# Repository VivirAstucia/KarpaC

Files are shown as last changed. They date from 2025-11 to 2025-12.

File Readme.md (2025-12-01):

# KarpaC - Prototype1
This is a smart chessboard project that takes chess to the next level by integrating a physical board with a digital interface. 

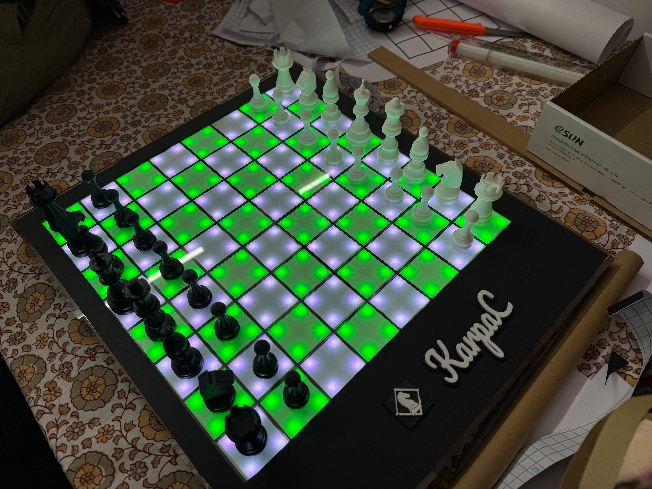
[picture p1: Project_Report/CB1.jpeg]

  
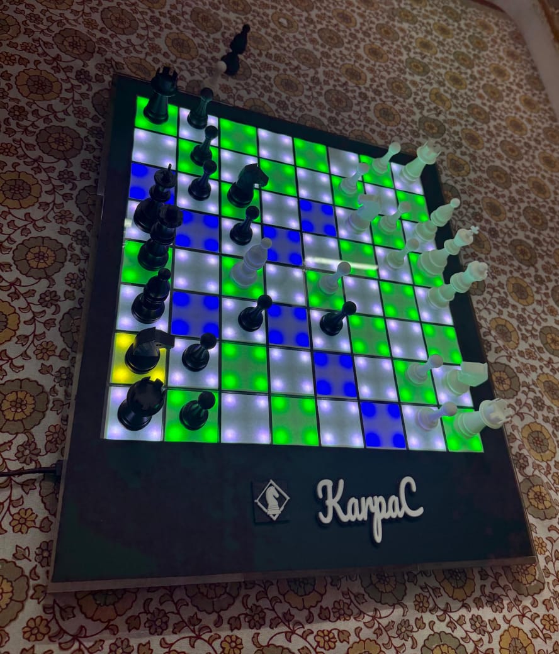
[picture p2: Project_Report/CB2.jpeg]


## Features
- **Real-time Game Tracking**: Automatically detects and records moves made on the physical board.
- **Digital Interface**: Provides a user-friendly interface to view and analyze games.
- **Move Validation**: Ensures that all moves made are legal according to chess rules.
- **Against Computer**: Play against a computer opponent with adjustable difficulty levels.
- **Game Analysis[TODO]**: Offers insights and suggestions based on the game state.
- **Multiplayer Support[TODO]**: Allows multiple players to join and play together online.

## Implementation
### Hardware
1. **Hall Effect Sensors**: Used to detect the position of chess pieces on the board.
2. **Ws2812B LEDs**: RGB LEDs for visual feedback and effects.
3. **Raspberry Pi 4b**: Acts as the main controller for processing inputs and managing the game state.
4. **Chess Pieces**: 3d printed pieces with embedded neodymium magnets for reliable detection.
5. **Chessboard**: A simple but elegant design with acrylic surfaces.
6. **Power Supply**: A 5V 3A power supply to power the Raspberry Pi and LEDs.

### Software
1. **Python**: Main programming language for the project.
   - `RPi.GPIO`, `chess`, `neopixel`
2. **Flask**: Web framework for creating the digital interface.
3. **Stockfish**: Chess engine for game analysis and computer opponent.

### Logic
1. **Current State**: Used boundary condition + pick/place data to determine the current state of the board.
2. **Move Detection**: Compares the previous and current state to detect moves.
3. **Move Validation**: Uses the `chess` library to validate moves.

## Issues and Fixes
- **Hall Sensor** - H[1][5] was not working in the pcb, and since no spare were available, it is set to always on in the code.
- **Temperature** - The board tends to heat up after prolonged use(40-50 mins). Since no ventilation was designed on the prototype.

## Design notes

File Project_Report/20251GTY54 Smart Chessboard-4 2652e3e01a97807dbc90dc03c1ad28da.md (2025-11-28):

# 20251GTY54: Smart Chessboard-4

**An MEP1001 project manufactured by** 

**Professor - Sunil Jha**

**TA - Devesh, Priyansh**

**Group - 29**

**Team -** 

**Priyanshu Raj (Group Leader)**

**Raghav Agarwal**

**Aadit Prakash Bhagade**

**Patil Kshitij Nikesh**

**Anuroop Dixit**

**2025MT11771**

**2025MT11351**

**2025CS11115**

**2025CS51201**

**2025MT11348**

---

# Navigation

---

# Market Research

## ChessNut Move

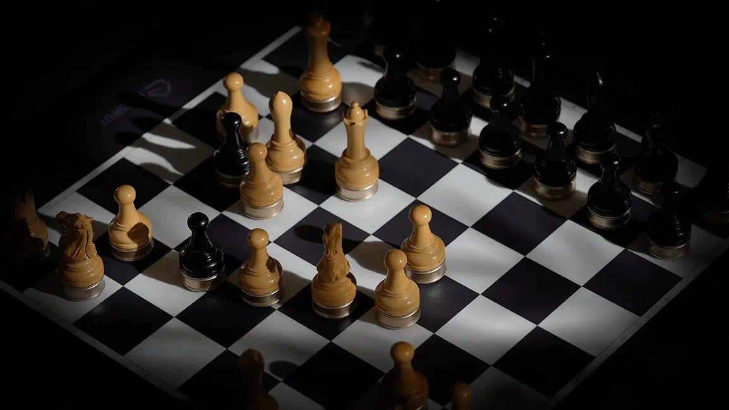
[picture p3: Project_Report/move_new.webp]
Source - [ChessNutech.com](https://www.chessnutech.com/)


Source - [ChessNutech.com](https://www.chessnutech.com/)

This board specializes in self-moving pieces. The pieces have little wheels attached at the bottom, which can be used to travel to any square on the board, even controlling the other pieces if necessary to move out of the way. It is also integrated with websites like [chess.com](http://chess.com/) and [lichess.org](http://lichess.org/) and can be used to play games and puzzles alike.

### Product Specifications: -

- Size: 63.2 cm x 52 cm x 2.2 cm
- Piece material: wood or plastic
- Features:
    - Automatic chess piece movement
    - Full piece recognition
    - Video integration
- Price: 53,000 INR

## GoChess

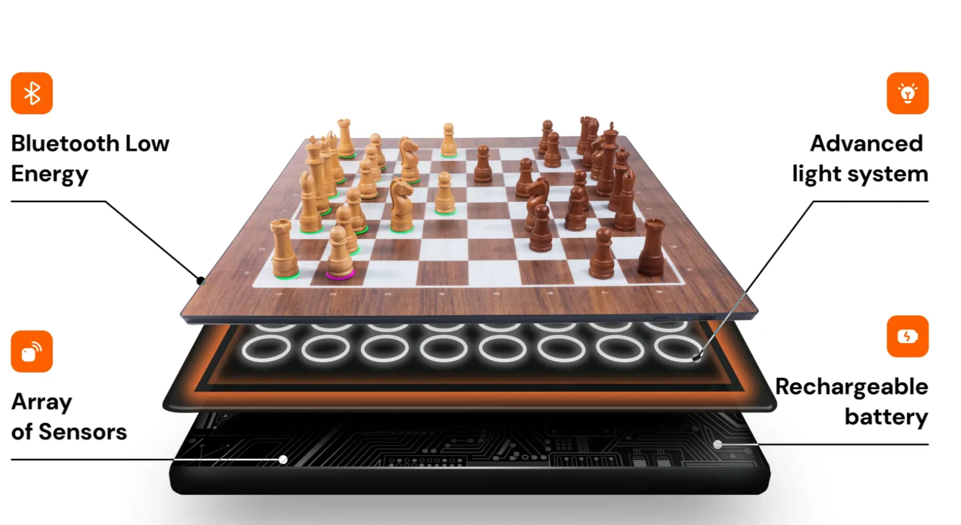
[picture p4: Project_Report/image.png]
Source - [GoChess](https://particula-tech.com/pages/gochess)


Source - [GoChess](https://particula-tech.com/pages/gochess)

A board focused on movement, recognition and suggestion, GoChess uses an enhanced motion technology to provide a comfortable user experience. It also displays the possible moves for a player once a piece is picked up. It is a one-of-a-kind product, that can be utilised in both online and in-player modes.

### Product Specification: -

- Board Size: 48 cm × 48 cm × 3.5 cm (standard) / 48 cm × 48 cm × 0.9 cm (slim model)
- Square Size: 4.8 cm × 4.8 cm
- Piece Material: Wooden and Plastic (Classic and Modern styles)
- Board Material: High quality plastic
- Sensors: Magnetic/Hall effect sensors to detect piece placement
- Connectivity: Bluetooth (BLE)
- Battery: Rechargeable (user serviceable) battery
- Charging Port: USB-C
- App Compatibility: iOS, Android, Web
- Price: 50,000 INR

### Features: -

- Self-moving pieces
- Intelligent Coaching lights
- App integration

## ChessUp

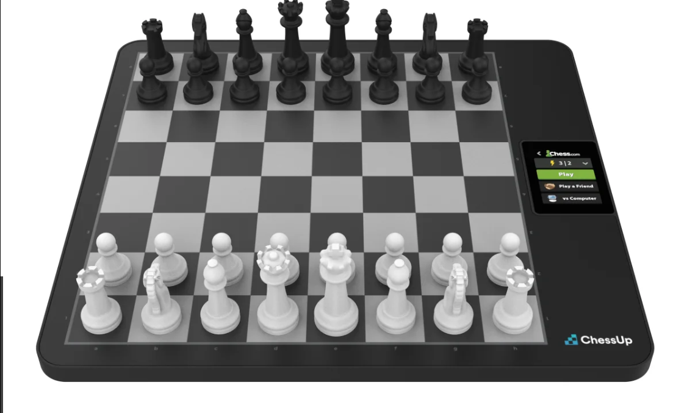
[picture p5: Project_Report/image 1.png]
Source - [PlayChessUp](https://playchessup.com/)


Source - [PlayChessUp](https://playchessup.com/)

The ChessUp board, affiliated with [chess.com](http://chess.com/) itself, is a new and innovative way to play chess. It excels at suggesting and recognizing moves. It can be connected with the [chess.com](http://chess.com/) server and can be used to play live games, over-the board, puzzles and bots. It provides the facility of adhering to all fair-play regulations according to its parent-company’s policy.

### Product Specification: -

- Weight: 1.13 kg
- Playable Area: 30.5cm × 30.5cm
- Square Size: 38.1 mm
- Battery Lifetime: 6 hours (USB‑C rechargeable)
- Connectivity: Wi‑Fi + Bluetooth
- Included Pieces: 34 with recognition chips
- Integration: Built-in Chess.com, some support for Lichess, no phone needed
- Price - Rs 35,125 INR

### Key Features: -

- Size: 39.6cm × 34.6cm × 1.8cm
- Touch sensing
- LED guidance
- AI training
- Touchscreen UI
- Stockfish integration

---

# Our Product - KarpaC

A smart-board which is light, seamlessly integrable with [chess.com](http://chess.com/) and [lichess](http://lichess.org/), connected to Stockfish, aesthetically pleasing and intelligent. It recognizes moves played and provides best-move suggestions by lighting up squares. It can be used for both over-the-board and online play. Its affordable nature sets it apart from its competitors.

## Product Specifications -

- Board Size: 36 cm * 40 cm * 5 cm
- Square Size: 4 * 4 cm
- Weight: Less than 2 kg
- Piece Material: 3D Printer Filament
- Board Material: Acrylic
- Sensors: Hall effect sensors to detect piece placement.
- Connectivity: Bluetooth (BLE) and Wi-Fi through ESP 32
- Battery: 4000mAh rechargeable battery (6+ hours of playtime)
- Charging Port: USB-C
- App Compatibility: iOS, Android, Web

## Key Features -

- LED move indicators
- Automatic Move Detection
- Inbuilt Chess Engine (Stockfish 15).
- Legal moves and best move suggestions.
- Buzzer sound on an illegal/invalid move.
- Integrated with chess.com and [lichess.org](http://lichess.org/) through Wi-Fi

## Initial Production Cost Estimate - 10,275 **INR**

| **Item** | **Function** | **Quantity** | Rate | Net Price |
| --- | --- | --- | --- | --- |
| LED ([WS2812B](https://evelta.com/ws2812b-v5-5v-0-24w-digital-rgb-led-4-pin-smd5050/)) | Light the squares of the board | 90 | 10 | 900 |
| Hall Sensors ([SL353LT](https://robu.in/product/honeywell-board-mount-hall-effect-sensor-sl353lt-micro-omni-dig-hall-eff-sens-ic-lwdcycle/)) | Detection of Pieces | 70 | 50 | 3500 |
| ESP 32 Board
[ESP32 - SquadPixel](https://www.amazon.in/SquadPixel-ESP-32-Bluetooth-Development-Board/dp/B071XP56LM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) | GPIO Control and Wifi Connectivity | 1 | 527 | 527 |
| Raspberry Pi 4 Model B with 2 GB RAM ([Raspberry Pi 4](https://robu.in/product/raspberry-pi-4-model-b-with-2-gb-ram/)) | Move Processing and running ChessEngine | 1 | 4714 | 4714 |
| SNOOGG Neodymium Round Magnet 10x1.5 mm ([Neodymium Magnet](https://www.amazon.in/SNOOGG-Neodymium-Magnet-N35-20/dp/B0DMS7YBXF/)) | Installed below each piece to make them detectable by the hall effect sensors. | 80 | 622.4 | 622.4 |
| 5V Active Electromagnetic Buzzer ([5v Buzzer](https://robu.in/product/5v-active-electromagnetic-buzzer-pack-of-5/)) | Played on invalid moves | 1 | 11 | 11 |
| **Items Already Available**  | **in LAB :-** |  |  |  |
| PCB Board | Connect the circuits | - | - | - |
| Acrylic Sheet | Base for Chessboard | - | - |  - |
| 3D Printer Filament Black  | Chess Pieces | - | - | - |
| 3D Printer Filament White | Chess Pieces  | - | - | - |
|  Capacitors:
    ◦ 4 × 47–100 µF ceramic 1206
    ◦ 4 × 330 Ω resistor
    ◦ 1 × 470–1000 µF | Circuit Safety and smoother switching of LEDs | - | - | - |

## BOM

[BoM_MEP1001.xlsx](BoM_MEP1001.xlsx)

## Target Price - 24,998 INR

---

# Project WorkFlow Flowchart

```mermaid
timeline
    title Project Workflow Flowchart.1
    Week 1 <br> Planning & Requirements <br>  .: Define scope and features of the chessboard.
				    : Research and finalize component list & budget
    Week 2 <br> Circuit & Fabrication: Draft and order the PCB design
         : 3D Print the chessboard and pieces
    Week 3 <br> Board Setup
	    : Install sensors, LEDs, and wiring
	    : Assemble circuits and battery
	 Week 4<br> Microcontroller Programming (Phase-1)
		 : Program sensor input & calibration
		 : Validate detection of all squares
		 
```

```mermaid
timeline
    title Project Workflow Flowchart.2
    Week 5 <br> Microcontroller Programming (Phase-2)
				    : Implement legal move logic & board state tracking
				    : Add LED feedback
    Week 6 <br> Software Integration
         : Connect board to PC/mobile app
			   : Sync with Stockfish for move visualization
    Week 7 <br> **Testing & Debugging
	    : Play full games to test detection
	    : Optimize stability & responsiveness
	 Week 8 <br> Final Touches & Presentation: Add enclosure/finishing
		 : Perform final debugging**
```

---

# Conceptual Product Design

## CAD Design

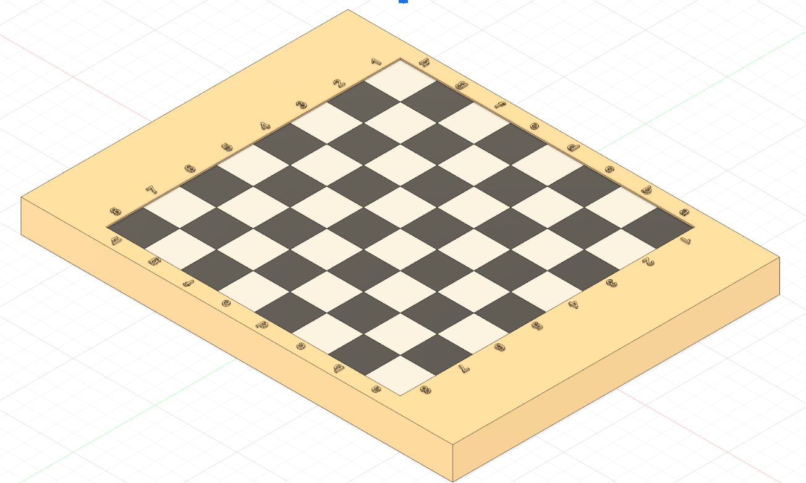
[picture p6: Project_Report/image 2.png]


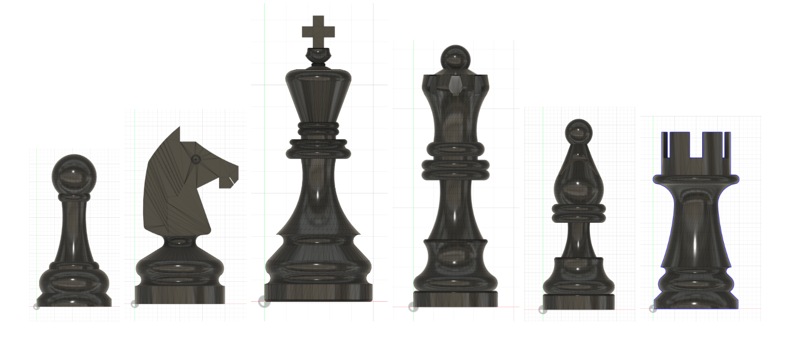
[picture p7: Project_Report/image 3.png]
Fusion 360


Fusion 360

[Chess Board.f3d](Chess_Board.f3d)

## PCB Design

1. Schematic
    
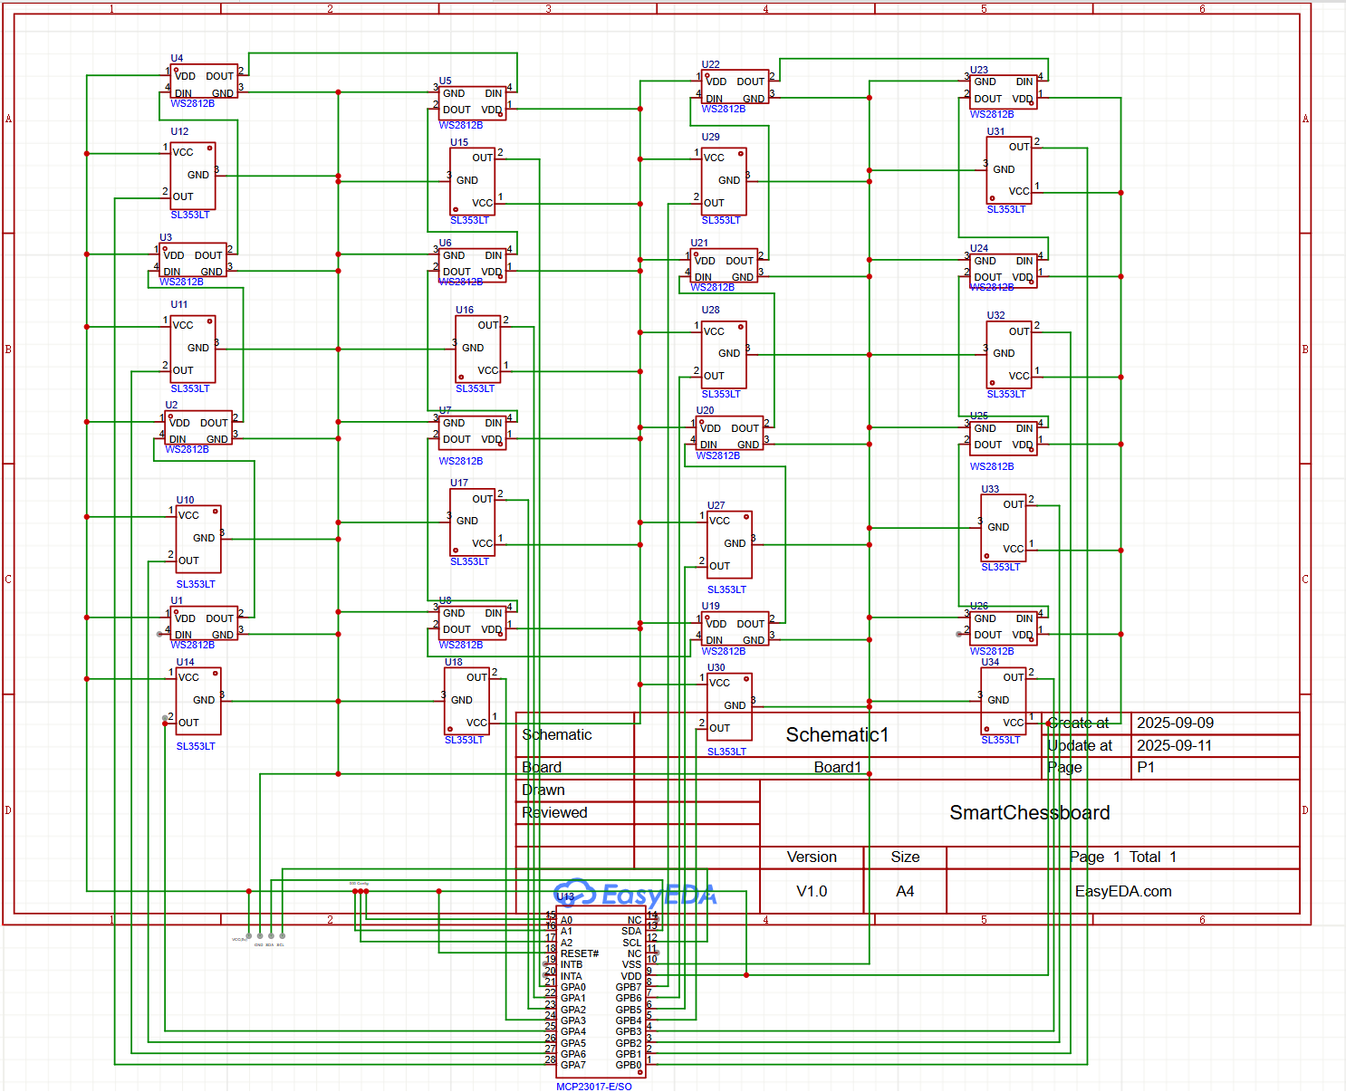
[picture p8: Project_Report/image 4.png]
    
    
    [EasyEDA](SCH_Schematic1_2025-09-11.pdf)
    
    EasyEDA
    
2. Wiring Layout
ESP32 (SDA) ---- SDA bus ---- MCP23017 (SDA pins, all 4 chips)
ESP32 (SCL) ---- SCL bus ---- MCP23017 (SCL pins, all 4 chips)
3.3V ---------- VCC (all sensors + MCP23017s)
GND ----------- GND (all sensors + MCP23017s)
Each Hall OUT → MCP23017 input pin
3. Board Design
    
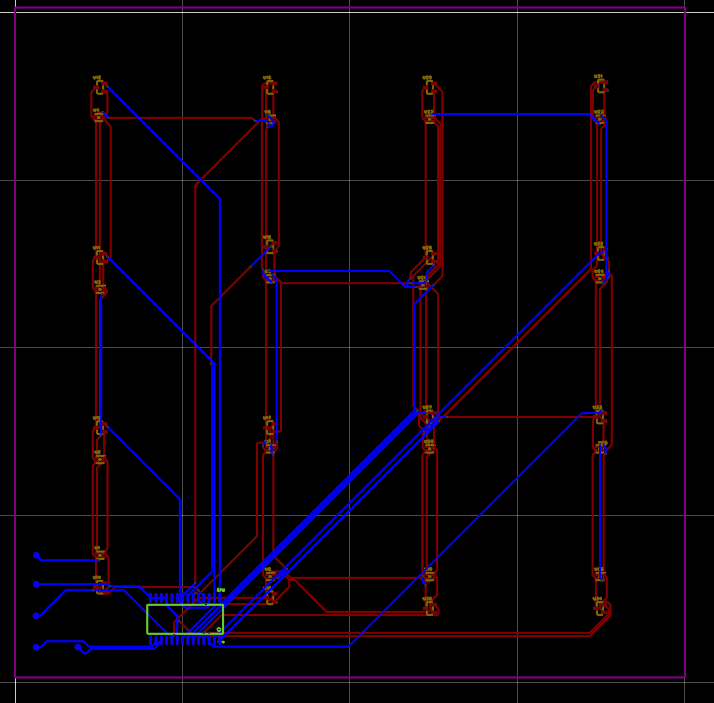
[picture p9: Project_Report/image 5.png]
    

We have 4 similar PCB’s with the minor difference of address configuration of MCP23017 (IO Expander).

## Electrical Design

From Each PCB, the following pads are present: -

| **5V** | Powers LEDs, Hall Sensors and MCP23017 (IO Expander) |
| --- | --- |
| **GND** | GND |
| **SDA** | SDA Line from MCP to ESP32 for hall input |
| **SCL** | SCL Line from MCP to ESP32 for data sync |
| **DIN** | Output line from ESP for controlling serial LEDs |

Controller Boards:- 

| ESP32 | Raspberry PI 4 (2GB) |
| --- | --- |
| Very fast for real time GPIO handling with very low latency.  | Multiple GPIO handling may lag. |
| Has wifi | Has wifi, but better range |
| Has lower memory (~526KB) | Has higher memory (2GB will be used)
Better for loading chess engine |
| Lower Processing Speed | Higher Processing Speed |
- A hybrid approach is the best here, where esp32 handles the gpio handling, and Raspberry Pi 4 handles the move processing and wifi output.

## On Paper Designs

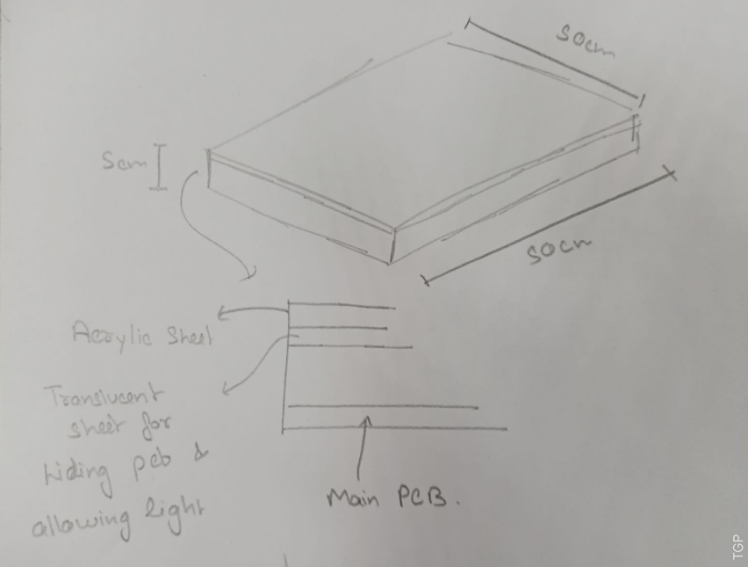
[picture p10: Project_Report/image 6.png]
Dimensions


Dimensions

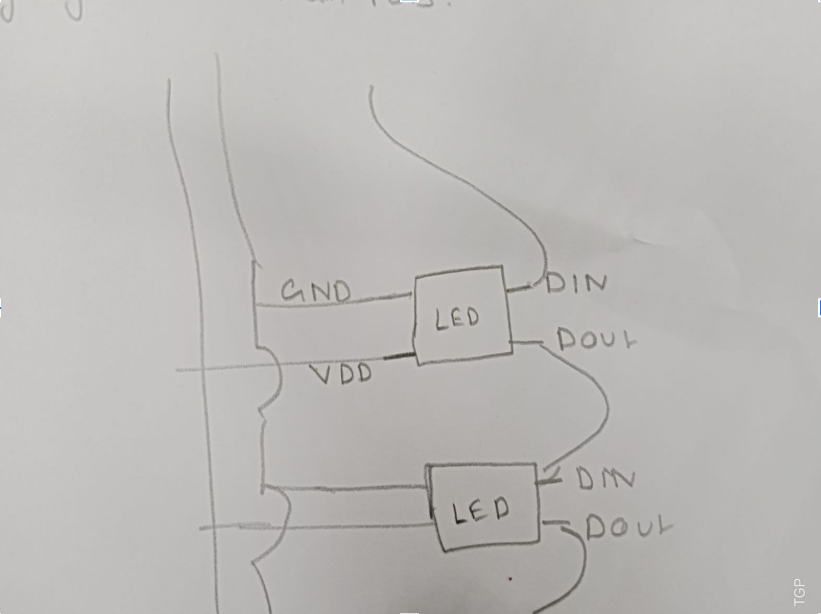
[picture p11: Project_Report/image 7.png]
Wiring Design


Wiring Design

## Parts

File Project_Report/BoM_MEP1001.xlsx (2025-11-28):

 | Project No. | 20251GTY54 |  |  |  | Project Name | Smart Chessboard-4
 | Team Leader's Name | Priyanshu Raj |  |  |  | Team Leader's Entry No. | 2025MT11771
S.No. | Part Number | Part Name / Description / Specification | Component Type | Qty | Unit | Manufacturer / Supplier | Notes/Remarks | Manufacturer or Supplier Link for Purchase | Approx. Cost
1 | Raspberry Pi 4 | Raspberry Pi 4 Model B with 2 GB RAM | Controller Board | 1 | pcs | Raspberry PI | For running chess model | Raspberry pi 4 - Robu.in (https://robu.in/product/raspberry-pi-4-model-b-with-2-gb-ram/) | INR 4714.0
2 | SS-12D00 1P2T | Slide Switch SS-12D00 1P2T | Switches | 2 | pcs | Vimex | For control | Switch - Robu.in (https://robu.in/product/1-month-warranty-255) | INR 6.0
3 | ESP-WROOM-32 | ESP 32 Board | Controller Board | 1 | pcs | Generic | For wifi connectivity and low latency gpio control | ESP 32 - Robu.in (https://robu.in/product/esp-wroom-32-wifi-bluetooth-networking-smart-component-development-board/) | INR 355.0
4 | 3C2S1P | Li-Ion Battery Pack, 7.4V 2000mAh | Electronic (Battery) | 1 | pcs | Pro-Range | Portabiilty | Battery - Robu.in (https://robu.in/product/pro-range-18650-li-ion-2000mah-7-4v-2s1p-protected-battery-pack-3c/) | INR 576.0
5 | N35 | SNOOGG Neodymium Round Magnet 10x1.5 mm | Mechanical (Magnets) | 80 | pcs | SNOOGG | For piece identification | Magnet - Amazon (https://www.amazon.in/SNOOGG-Neodymium-Magnet-N35-20/dp/B0DMS7YBXF/) | INR 622.4
6 | R13-507 | Red R13-507 16mm No Lock Push, Button Momentary Switch 3A, 250V | Buttons | 2 | pcs | Generic | For control | Push button (Red) - Robu.in (https://robu.in/product/red-r13-507-16mm-no-lock-push-button-momentary-switch-3a-250v/) | INR 34.0
7 | SKU: 616166 | 5V Active Electromagnetic Buzzer | Electronic (Buzzer) | 1 | pcs | Generic | Utility | Buzzer - Robu.in (https://robu.in/product/5v-active-electromagnetic-buzzer-pack-of-5/) | INR 11.0
8 | MCP23017 | MCP23017 16 Bit - I/O Expander | Electronic (SMT) | 4 | pcs | Generic | For PCB SMD | MCP23017 - Robu.in (https://robu.in/product/mcp23017-16-bit-input-output-expander-with-i2c-interface-ic-dip-28-package/) | INR 1276.0

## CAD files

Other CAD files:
Project_Report/Chess_Board.f3d

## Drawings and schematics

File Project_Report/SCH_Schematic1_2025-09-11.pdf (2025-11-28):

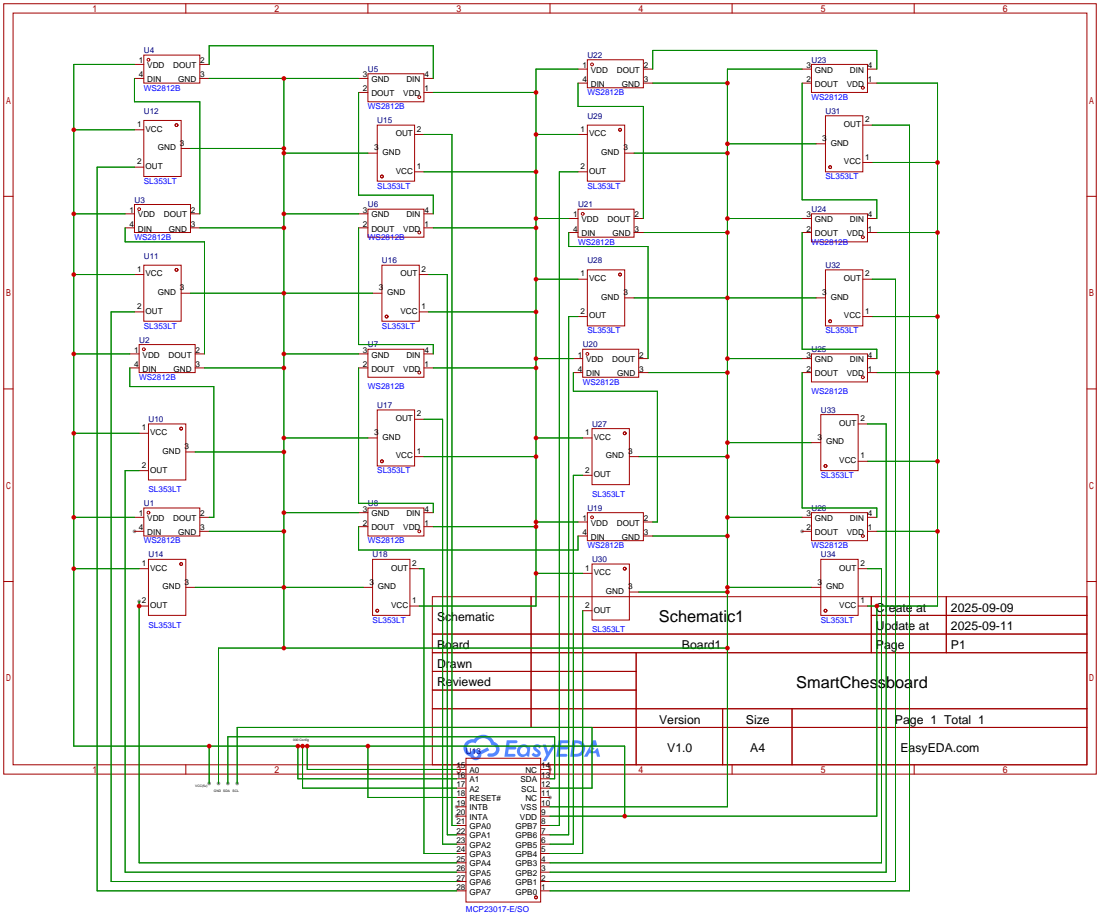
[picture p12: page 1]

2 | 1 VCC SL353LT

Update at | | | 2025-09-11

Board | | Board1 | | Page | P1
Drawn | | | | SmartChessboard
Reviewed

Version | Size | Page 1 Total 1
V1.0 | A4 | EasyEDA.com

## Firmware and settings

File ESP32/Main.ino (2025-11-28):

#include <Arduino.h>
#include <Adafruit_NeoPixel.h>

const int side1 = 8, side2 = 4;

int LED = 23;
int count = side1*side1*4;

const int H_IN[] = {15, 2, 4, 5};
const int H_OUT[] = {13, 12, 14, 27, 26, 25, 33, 32};


int hall_grid[side2][side1] = {
    {0, 0, 0, 0, 0, 0, 0, 0},
    {0, 0, 0, 0, 0, 0, 0, 0},
    {0, 0, 0, 0, 0, 0, 0, 0},
    {0, 0, 0, 0, 0, 0, 0, 0}
};


int square[side2][side1][4] = {
    {{0, 1, 30, 31}, {2, 3, 28, 29}, {4, 5, 26, 27}, {6, 7, 24, 25}, {8, 9, 22, 23}, {10, 11, 20, 21}, {12, 13, 18, 19}, {14, 15, 16, 17}},
    // {{16, 17, 30, 31}, {18, 19, 28, 29}, {20, 21, 26, 27}, {22, 23, 24, 25}},
    {{32, 33, 62, 63}, {34, 35, 60, 61}, {36, 37, 58, 59}, {38, 39, 56, 57}, {40, 41, 54, 55}, {42, 43, 52, 53}, {44, 45, 50, 51}, {46, 47, 48, 49}},
    // {{32, 33, 46, 47}, {34, 35, 44, 45}, {36, 37, 42, 43}, {38, 39, 40, 41}},
    {{64, 65, 94, 95}, {66, 67, 92, 93}, {68, 69, 90, 91}, {70, 71, 88, 89}, {72, 73, 86, 87}, {74, 75, 84, 85}, {76, 77, 82, 83}, {78, 79, 80, 81}},
    // {{48, 49, 62, 63}, {50, 51, 60, 61}, {52, 53, 58, 59}, {54, 55, 56, 57}}
    {{96, 97, 126, 127}, {98, 99, 124, 125}, {100, 101, 122, 123}, {102, 103, 120, 121}, {104, 105, 118, 119}, {106, 107, 116, 117}, {108, 109, 114, 115}, {110, 111, 112, 113}}
};


Adafruit_NeoPixel strip(count, LED, NEO_GRB + NEO_KHZ800);
auto yellow = strip.Color(255, 150, 0);
auto red = strip.Color(255, 0, 0);
auto blue = strip.Color(0, 0, 255);
auto green = strip.Color(0, 255, 0);
auto pink = strip.Color(255, 0, 255);
auto purple = strip.Color(75, 0, 130);
auto orange = strip.Color(255, 165, 0);



void read_hall_sensors() {
    for (int i = 0; i < side2; i++) {
        digitalWrite(H_IN[i], HIGH);
        delay(5);
        for (int j = 0; j < side1; j++) hall_grid[i][j] = digitalRead(H_OUT[j]);
        digitalWrite(H_IN[i], LOW);
    }

    Serial.println("Hall Sensor Grid: ");
    for (int i = 0; i < side2; i++) {
        for (int j = 0; j < side1; j++) {
            Serial.print(hall_grid[i][j]); Serial.print(" ");
        }
        Serial.println(); Serial.println();
    }
}

void update_leds() {
    strip.clear();
    for (int i = 0; i < side2; i++) {
        for (int j = 0; j < side1; j++) {
            auto set_color = hall_grid[i][j] ? red : blue;
            for (int led_idx : square[i][j]) strip.setPixelColor(led_idx, set_color);
        }
    }
    strip.show();
}

void led_test() {
    for (auto& square_row : square) {
        for (auto& leds : square_row) {
            strip.clear();
            for (int led_index : leds) {
                for (auto color: {red, green, blue, yellow}) {
                    strip.setPixelColor(led_index, color);
                    strip.show();
                    delay(500);
                }
            }
        }
    }
}

void led_test1(){
    // light up all leds changing color - R,G,B,Y,O,P,W,off, with 500 ms interval
    for (auto color : {red, green, blue, yellow, orange, pink, purple}) {
        strip.fill(color);
        strip.show();
        delay(500);
    }
}

void led_test2(){
    int x = 2;
    int y = 3;
    digitalWrite(H_IN[y], HIGH);
    int val = digitalRead(H_OUT[x]);
    if (val == 0) {
    // for (auto color : {red, green, blue, yellow, orange, pink, purple}) {
        for (int led_idx : square[y][x]) {
            strip.setPixelColor(led_idx, red);
        }
        strip.show();
    }
    else {
        for (int led_idx : square[y][x]) {
            strip.setPixelColor(led_idx, blue);
        }
        strip.show();
    }

    // }
}

void setup() {
    Serial.begin(115200);
    Serial.println("Test");

    strip.begin();
    strip.show();

    for (int pin : H_IN) {
        pinMode(pin, OUTPUT);
        digitalWrite(pin, LOW);
    }

    for (int pin : H_OUT) pinMode(pin, INPUT_PULLUP);
    // strip.setBrightness(70);
}

void loop() {
    read_hall_sensors();
    update_leds();
    delay(10);
    // led_test1();
    // delay(50);
}

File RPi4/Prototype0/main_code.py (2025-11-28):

import time
import board
import busio
import sensor_matrix
import led_matrix
import chess
from stockfish import Stockfish

STOCKFISH_PATH = r".\engine\stockfish.exe"
LED_COUNT = 64
LED_PIN = board.D18  # GPIO 18 (PWM-capable pin)
LED_BRIGHTNESS = 0.3 

BLACK = (0, 0, 0)
WHITE = (150, 150, 150)
RED = (255, 0, 0)
GREEN = (0, 255, 0)
BLUE = (0, 0, 255)
YELLOW = (255, 255, 0)
CYAN = (0, 255, 255)
MAGENTA = (255, 0, 255)
ORANGE = (255, 165, 0)

class SmartChessGame:
    def __init__(self):
        print("Initializing Smart Chessboard...")

        self.i2c = busio.I2C(board.SCL, board.SDA)
        self.sensors = sensor_matrix.SensorMatrix(self.i2c)
        self.leds = led_matrix.LedMatrix(LED_PIN, LED_COUNT, LED_BRIGHTNESS)
        self.stocky = Stockfish(path=STOCKFISH_PATH)

        self.board = chess.Board() 
            
        self.previous_board_state = self.sensors.read_board_state()
        self.current_board_state = self.previous_board_state.copy()
        
        self.picked_up_square_index = None 
        self.best_move_hint = None 

        print("Initialization complete. Starting game loop.")
        self.leds.fill(WHITE) 
        self.leds.show()
        time.sleep(1)
        self.leds.clear()
        self.leds.show()

    def run_game_loop(self):
        """The main polling loop that detects moves."""
        try:
            while not self.board.is_game_over():
                self.current_board_state = self.sensors.read_board_state()
                
                if self.current_board_state != self.previous_board_state:
                    print("State change detected!")
                    self.handle_board_change()
                
                self.previous_board_state = self.current_board_state.copy()
                
                time.sleep(0.1)

            print("Game Over.")
            print(f"Result: {self.board.result()}")
            self.leds.play_game_over_animation()

        except KeyboardInterrupt:
            print("\nGame interrupted by user.")
        finally:
            self.shutdown()

    def handle_board_change(self):
        """This is the core logic for detecting a move."""
        
        diff_indices = [i for i in range(64) if self.current_board_state[i] != self.previous_board_state[i]]
        
        if len(diff_indices) == 0:
            return # Should not happen, but good to check
        
        if len(diff_indices) == 1 and self.picked_up_square_index is None:
            index = diff_indices[0]
            if not self.current_board_state[index]: # Piece was lifted
                self.picked_up_square_index = index
                self.handle_piece_pickup(index)

        elif len(diff_indices) == 1 and self.picked_up_square_index is not None:
            to_index = diff_indices[0]
            if to_index == self.picked_up_square_index:
                print("Piece returned to original square.")
                self.picked_up_square_index = None
                self.leds.clear()
                self.leds.show()
            elif self.current_board_state[to_index]: # Piece was placed
                from_index = self.picked_up_square_index
                self.picked_up_square_index = None # No longer holding a piece
                self.handle_piece_drop(from_index, to_index)

        else:
            print(f"Ignoring ambiguous state change (diff: {len(diff_indices)}).")
            # Clear any "picked up" state to reset
            if self.picked_up_square_index is not None:
                 self.picked_up_square_index = None
                 self.leds.clear()
                 self.leds.show()


    def handle_piece_pickup(self, index):
        """Called when a piece is lifted from 'index'."""
        print(f"Piece picked up from {self.leds.index_to_chess_square(index)}")
        from_square = self.leds.index_to_chess_square(index)
        
        # Check if it's the correct player's piece
        piece = self.board.piece_at(from_square)
        if piece is None or piece.color != self.board.turn:
            print("Picked up empty square or wrong color piece.")
            self.leds.clear()
            self.leds.set_square(index, ORANGE) # Show "wrong piece"
            self.leds.show()
            self.picked_up_square_index = None
            return

        legal_moves_for_piece = [
            move for move in self.board.legal_moves 
            if move.from_square == from_square
        ]
        self.leds.show_legal_moves(index, legal_moves_for_piece, self.current_board_state)
        
        

    def handle_piece_drop(self, from_index, to_index):
        """Called when a piece is moved from 'from_index' to 'to_index'."""

        # Clear all move/hint LEDs
        self.leds.clear()
        self.leds.show()

        from_square = self.leds.index_to_chess_square(from_index)
        to_square = self.leds.index_to_chess_square(to_index)

        # Create the move object. Handle promotions (default to Queen).
        move = chess.Move(from_square, to_square)
        if self.board.piece_type_at(from_square) == chess.PAWN:
            if chess.square_rank(to_square) == 7 and self.board.turn == chess.WHITE:
                move.promotion = chess.QUEEN
            elif chess.square_rank(to_square) == 0 and self.board.turn == chess.BLACK:
                move.promotion = chess.QUEEN
        
        # Check if the move is legal
        if move in self.board.legal_moves:
            print(f"Legal move: {move.uci()}")
            self.board.push(move)
            self.leds.highlight_last_move(from_index, to_index)
        else:
            print(f"ILLEGAL move attempted: {move.uci()}")
            self.leds.play_illegal_move_animation()
        time.sleep(1.0)
        self.leds.clear()
        self.leds.show()
        self.start_stockfish_analysis()
        
    def start_stockfish_analysis(self):
        """Starts a new thread to get a hint from Stockfish."""
        self.stocky.set_fen_position(self.board.fen())
        self.best_move_hint = self.stocky.get_best_move_time(1000)
        self.leds.show_best_move_hint(self.best_move_hint)


    def shutdown(self):
        """Cleans up resources on exit."""
        print("Shutting down...")
        if hasattr(self, 'leds'):
            self.leds.clear()
            self.leds.show()
            print("LEDs cleared.")

# -----------------------------------------------------------------------------
# 5. MAIN EXECUTION
# -----------------------------------------------------------------------------

if __name__ == "__main__":
    game = None
    try:
        game = SmartChessGame()
        game.run_game_loop()
    except Exception as main_e:
        print(f"An unexpected error occurred: {main_e}")
    finally:
        if game:
            game.shutdown()
        print("Program terminated.")

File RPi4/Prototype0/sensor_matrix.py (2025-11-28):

import adafruit_mcp23017
from digitalio import Direction, Pull

SENSOR_ACTIVE_LOW = True
I2C_ADDRESSES = [0x20, 0x21, 0x22, 0x23]
class SensorMatrix:
    """Manages the 4x MCP23017 I/O expanders to read 64 sensors."""
    
    def __init__(self, i2c):
        self.mcps = []
        self.pins = []
        try:
            for addr in I2C_ADDRESSES:
                mcp = adafruit_mcp23017.MCP23017(i2c, address=addr)
                self.mcps.append(mcp)
            print(f"Successfully initialized {len(self.mcps)} MCP23017 expanders.")
        except Exception as e:
            print(f"FATAL ERROR: Could not initialize MCP23017. Check I2C wiring and addresses.")
            print(f"Error: {e}")
            raise
            
        # Store all 64 pin objects for faster access
        for mcp in self.mcps:
            for i in range(16): # GPA0-7, GPB0-7
                pin = mcp.get_pin(i)
                pin.direction = Direction.INPUT
                pin.pull = Pull.UP # Use internal pull-ups
                self.pins.append(pin)

    def read_board_state(self):
        """
        Reads all 64 sensors and returns a list of booleans.
        True = Occupied (piece present)
        False = Empty
        """
        state = [False] * 64
        for i in range(64):
            pin_value = self.pins[i].value
            # If sensor is active-low, a LOW value (False) means a piece is present
            if SENSOR_ACTIVE_LOW:
                state[i] = not pin_value
            else:
                state[i] = pin_value
        return state
